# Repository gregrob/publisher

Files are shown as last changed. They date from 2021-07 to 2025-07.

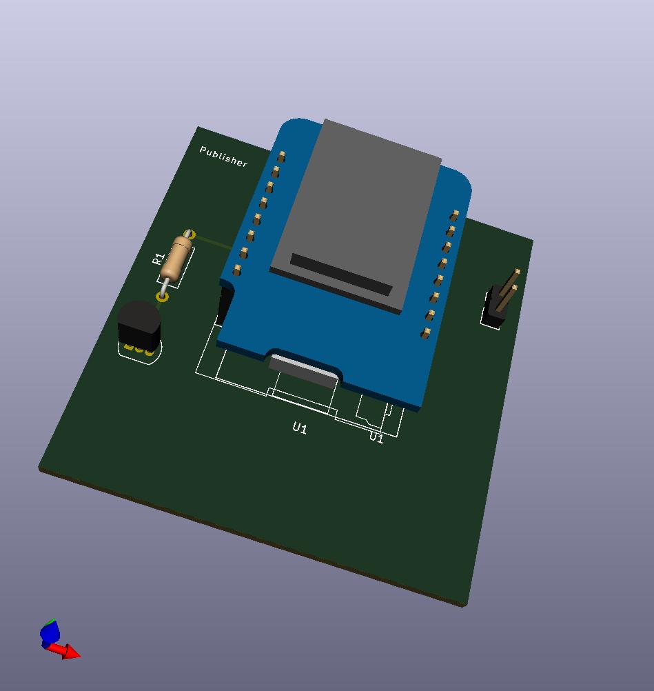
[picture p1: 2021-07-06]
hardware/publisher/publisher.jpg

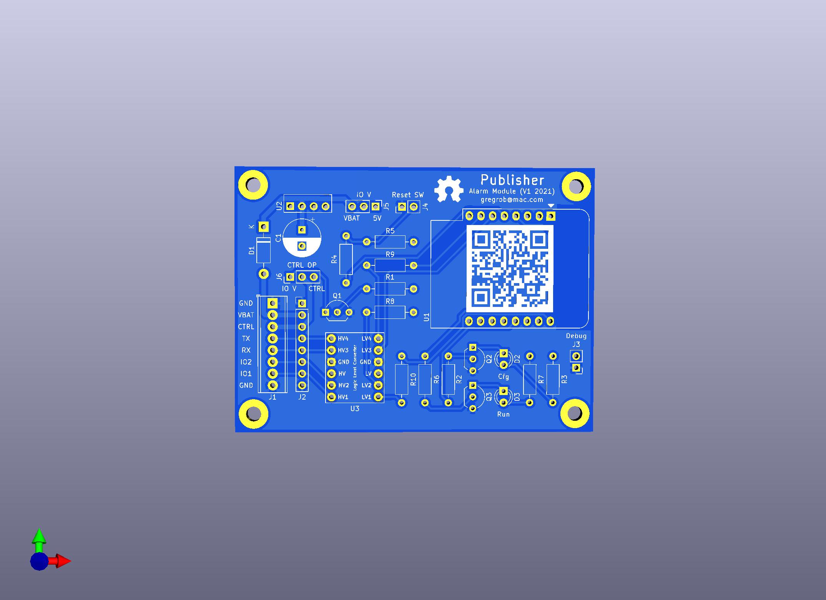
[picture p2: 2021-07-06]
hardware/publisher/publisher-2jpg.jpg

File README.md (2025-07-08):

# Publisher

IoT gadget that sends / receives / acts on MQTT messages.

Using arduino library and PlatformIO to allow easy porting between ESP8266 / ESP32 / Raspberry Pi Pico.

Applications:

1. Alarm interface
* PIR states.
* Remote arm / disarm.

2. Garage door
* Door state.
* Open / Close.

3. Tank Water Level
* Water level.

## Documentation

Detailed technical documentation for various system components and features:

### Device Control & Management
- **[Reset Control via MQTT](docs/reset_control/reset_control_mqtt.md)** - Remote device reset functionality including WiFi and NVM clearing

### Hawkbit
- **[Hawkbit Client Flow](docs/hawkbit/hawkbit_client_flow.svg)** - Over-the-air (OTA) update client flow diagram showing device update process with hawkbit

### Communication Protocols
- *(coming soon)*

### Hardware Interfaces  
- *(coming soon)*

### System Features
- *(coming soon)*

### Development & Debugging
- *(coming soon)*

### Integration Examples
- *(coming soon)*

## Software Architecture
Software Architecture

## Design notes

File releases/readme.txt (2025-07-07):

--------------------------------------------------
000.006.005
2021-06-06

- First release for the alarm module.
- Currently running on the alarm module.

--------------------------------------------------
000.007.005
2022-08-20

- First release to include the garage door.
- Includes test code for the ultrasonics.

--------------------------------------------------

000.007.006
2022-09-08

- The input debounce configuration was incorrectly
  set to 0.  This releases fixes this and 
  configures the reset pin to 40ms and alarm 
  sounder pin to 500ms.

--------------------------------------------------

000.007.007
2024-07-07

- Release to include pub-garage-door-active-v2
- Pin platform to espressif8266@2.6.3

- BUG: Runtime is in ms not us as variable would
       suggest

--------------------------------------------------

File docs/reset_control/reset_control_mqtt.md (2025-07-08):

# Reset Control via MQTT

This document describes how to control device resets remotely using MQTT commands in the Publisher project.

## Overview

The Publisher device supports remote reset functionality through MQTT messages. This allows for different types of resets to be triggered remotely, from a simple restart to clearing WiFi credentials and NVM settings.

## MQTT Topic Structure

The device subscribes to the following MQTT topic for reset commands:

```
[mqtt_prefix]/[hostname]/module command
```

Where:
- `mqtt_prefix`: Configured MQTT topic root (from NVM settings)
- `hostname`: Device hostname (derived from WiFi module details)

## Reset Command Format

Reset commands are sent as JSON messages with the following structure:

```json
{
  "reset": <reset_type>
}
```

Where `<reset_type>` is an integer representing the type of reset to perform.

## Reset Types

The following reset types are supported:

| Reset Type | Value | Description |
|---|---|---|
| `rstTypeNone` | 0 | No reset (cancels pending reset) |
| `rstTypeReset` | 1 | Simple device restart |
| `rstTypeResetWiFi` | 2 | Restart + clear WiFi settings |
| `rstTypeResetWiFiNvm` | 3 | Restart + clear WiFi + NVM settings |

## Reset Behavior

### Simple Reset (`rstTypeReset` = 1)
- Performs immediate device restart
- Preserves all configuration settings
- Device will reconnect with existing settings

### WiFi Reset (`rstTypeResetWiFi` = 2)
- Clears WiFi configuration settings
- Performs device restart
- Device will enter WiFi configuration mode on next boot
- NVM settings are preserved

### WiFi + NVM Reset (`rstTypeResetWiFiNvm` = 3)
- Clears all WiFi configuration settings
- Clears all NVM (Non-Volatile Memory) settings
- Performs device restart
- Device will enter initial setup mode

## Example Commands

### Simple Restart
```bash
# Using mosquitto_pub
mosquitto_pub -h <mqtt_broker> -t "devices/publisher001/module command" -m '{"reset": 1}'
```

### Clear WiFi and Restart
```bash
mosquitto_pub -h <mqtt_broker> -t "devices/publisher001/module command" -m '{"reset": 2}'
```

### Factory Reset (Clear WiFi + NVM)
```bash
mosquitto_pub -h <mqtt_broker> -t "devices/publisher001/module command" -m '{"reset": 3}'
```

### Cancel Pending Reset
```bash
mosquitto_pub -h <mqtt_broker> -t "devices/publisher001/module command" -m '{"reset": 0}'
```

## Reset State Machine

The reset controller implements a state machine with the following states:

- **stmResetIdle**: Normal operation, waiting for reset requests
- **stmReset**: Reset type 1 requested
- **stmResetWiFi**: Reset type 2 requested  
- **stmResetWiFiNvm**: Reset type 3 requested
- **stmResetAllowCancel**: Cancellation period before executing reset
- **stmResetAction**: Performing the actual reset

## Physical Reset Switch Integration

The system also supports physical reset switch functionality:

- **2 seconds**: Triggers WiFi reset (`rstTypeResetWiFi`)
- **8 seconds**: Triggers WiFi + NVM reset (`rstTypeResetWiFiNvm`)
- Physical switch can be enabled/disabled via configuration

## Cancellation Window

When a reset is requested via MQTT, there is a cancellation period before the reset is executed:

- **Fast cancel**: 2 seconds for switch-triggered resets
- **Slow cancel**: 5 seconds for MQTT-triggered resets

During this window, sending `{"reset": 0}` will cancel the pending reset.

## Debug Information

Reset operations generate debug messages that can be monitored:

```
resetCtrl: State change to <state> (request type <type>)
resetCtrl: Rebooting unit + clearing WiFi settings...
resetCtrl: Reset will occur in Xs
```

## Priority Handling

The reset controller processes requests in the following priority order:

1. **OTA Reboot**: Highest priority when OTA update requires restart
2. **MQTT Reset Request**: Medium priority for remote reset commands
3. **Physical Switch**: Lowest priority for manual reset operations

## Error Handling

- Invalid reset type values are ignored
- Reset requests are only accepted when the state machine is in idle state
- Message buffer overflow protection prevents malformed commands
- JSON parsing errors are logged and rejected

## Security Considerations

- MQTT authentication should be enabled on the broker
- Consider using TLS/SSL for MQTT connections
- Physical access to the reset switch provides full device control
- WiFi + NVM reset will require device reconfiguration

## Integration Example

Here's a Python example for sending reset commands:

```python
import paho.mqtt.client as mqtt
import json

def send_reset_command(mqtt_client, device_hostname, reset_type):
    """
    Send a reset command to a device
    
    Args:
        mqtt_client: Connected MQTT client
        device_hostname: Target device hostname
        reset_type: Reset type (0-3)
    """
    topic = f"devices/{device_hostname}/module command"
    payload = json.dumps({"reset": reset_type})
    
    mqtt_client.publish(topic, payload)
    print(f"Sent reset command {reset_type} to {device_hostname}")

# Usage
client = mqtt.Client()
client.connect("mqtt_broker_address", 1883, 60)

# Simple restart
send_reset_command(client, "publisher001", 1)

# Factory reset
send_reset_command(client, "publisher001", 3)
```

## Related Modules

- **MQTT Module**: Handles message reception and topic subscription
- **WiFi Module**: Manages WiFi configuration and connection
- **NVM Module**: Handles non-volatile memory operations
- **Debug Module**: Provides logging and status reporting
- **Status Controller**: Manages LED status indicators during reset operations

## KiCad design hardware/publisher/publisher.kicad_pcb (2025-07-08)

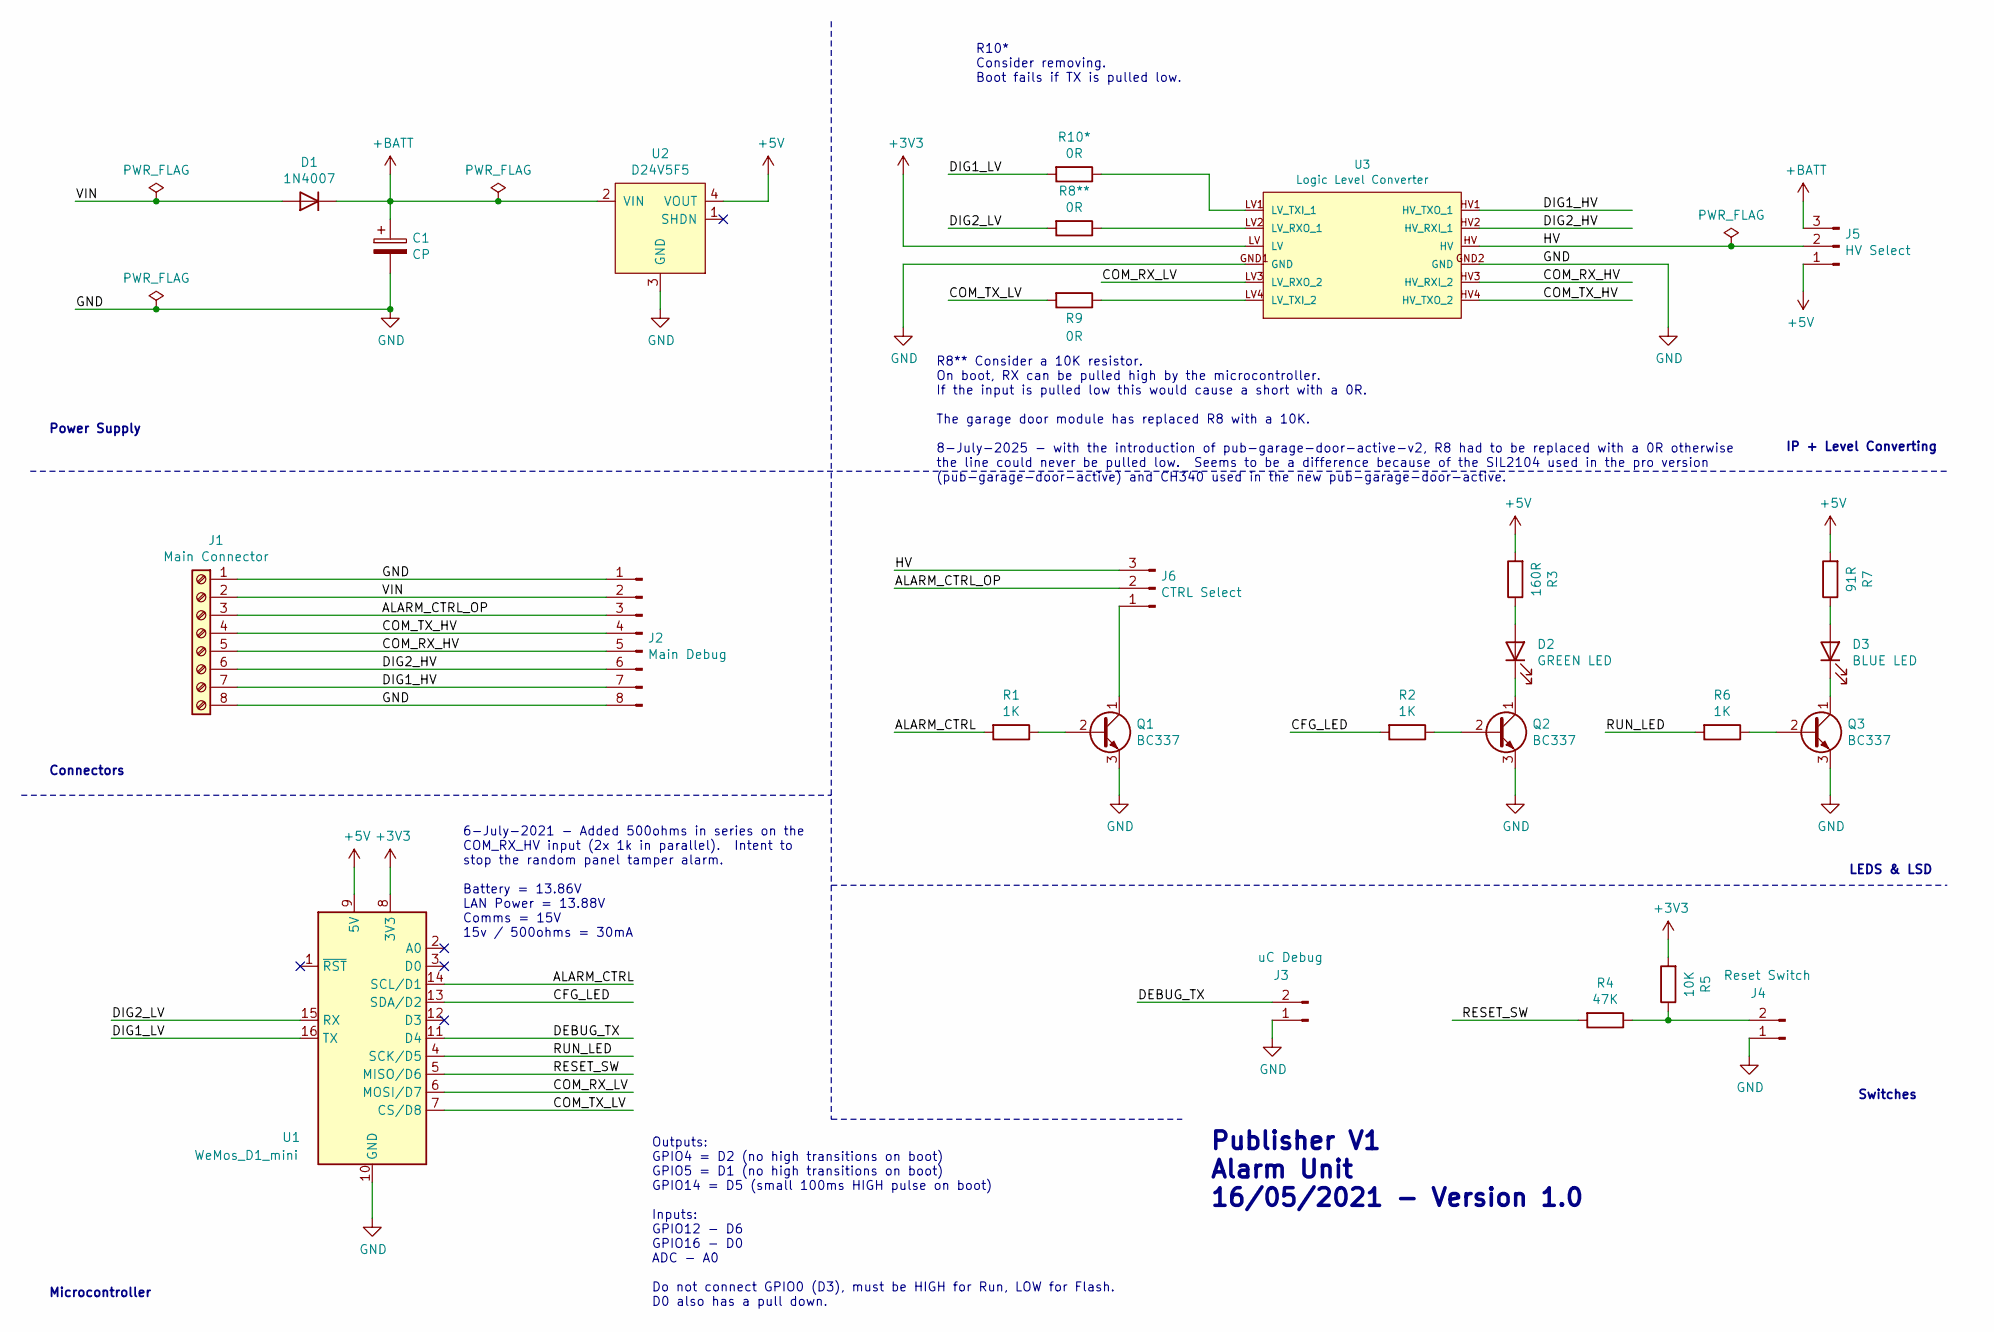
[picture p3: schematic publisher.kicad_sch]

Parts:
C1: CP; CP_Radial_D8.0mm_P3.50mm
D1: 1N4007; D_DO-41_SOD81_P10.16mm_Horizontal
D2: GREEN LED; LED_D3.0mm_Clear
D3: BLUE LED; LED_D3.0mm_Clear
J1: Main Connector; TerminalBlock_Phoenix_MPT-0,5-8-2.54_1x08_P2.54mm_Horizontal
J2: Main Debug; PinHeader_1x08_P2.54mm_Vertical
J3: uC Debug; PinHeader_1x02_P2.54mm_Vertical
J4: Reset Switch; PinHeader_1x02_P2.54mm_Vertical
J5: HV Select; PinHeader_1x03_P2.54mm_Vertical
J6: CTRL Select; PinHeader_1x03_P2.54mm_Vertical
Q1, Q2, Q3: BC337; TO-92_Inline_Wide
R1, R2, R6: 1K; R_Axial_DIN0207_L6.3mm_D2.5mm_P10.16mm_Horizontal
R3: 160R; R_Axial_DIN0207_L6.3mm_D2.5mm_P10.16mm_Horizontal
R4: 47K; R_Axial_DIN0207_L6.3mm_D2.5mm_P10.16mm_Horizontal
R5: 10K; R_Axial_DIN0207_L6.3mm_D2.5mm_P10.16mm_Horizontal
R7: 91R; R_Axial_DIN0207_L6.3mm_D2.5mm_P10.16mm_Horizontal
R8**, R9, R10*: 0R; R_Axial_DIN0207_L6.3mm_D2.5mm_P10.16mm_Horizontal
U1: WeMos_D1_mini; WEMOS_D1_mini_light
U2: D24V5F5
U3: Logic Level Converter; SPARKFUN_LOGIC_LEVEL_CONVERTER

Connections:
+3V3: R5.2, U1.8 (3V3), U3.LV
+5V: J5.1, R3.2, R7.2, U1.9 (5V), U2.4 (VOUT)
+BATT: C1.1, D1.1 (K), J5.3, U2.2 (VIN)
/ALARM_CTRL: R1.2, U1.14 (SCL/D1)
/ALARM_CTRL_OP: J1.3, J2.3, J6.2
/CFG_LED: R2.2, U1.13 (SDA/D2)
/COM_RX_HV: J1.5, J2.5, U3.HV3 (HV_RXI_2)
/COM_RX_LV: U1.6 (MOSI/D7), U3.LV3 (LV_RXO_2)
/COM_TX_HV: J1.4, J2.4, U3.HV4 (HV_TXO_2)
/COM_TX_LV: R9.2, U1.7 (CS/D8)
/DEBUG_TX: J3.2, U1.11 (D4)
/DIG1_HV: J1.7, J2.7, U3.HV1 (HV_TXO_1)
/DIG1_LV: R10*.2, U1.16 (TX); also elsewhere on the board
/DIG2_HV: J1.6, J2.6, U3.HV2 (HV_RXI_1)
/DIG2_LV: R8**.2, U1.15 (RX); also elsewhere on the board
/HV: J5.2, J6.3, U3.HV
/RESET_SW: R4.2, U1.5 (MISO/D6)
/RUN_LED: R6.2, U1.4 (SCK/D5)
/VIN: D1.2 (A), J1.2, J2.2
GND: C1.2, J1.1, J1.8, J2.1, J2.8, J3.1, J4.1, Q1.3 (E), Q2.3 (E), Q3.3 (E), U1.10 (GND), U2.3 (GND), U3.GND1 (GND), U3.GND2 (GND)
unnamed: D2.1 (K), Q2.1 (C)
unnamed: D2.2 (A), R3.1
unnamed: D3.1 (K), Q3.1 (C)
unnamed: D3.2 (A), R7.1
unnamed: J4.2, R4.1, R5.1
unnamed: J6.1, Q1.1 (C)
unnamed: Q1.2 (B), R1.1
unnamed: Q2.2 (B), R2.1
unnamed: Q3.2 (B), R6.1
unnamed 29: R8**.1, U3.LV2 (LV_RXO_1); also elsewhere on the board
unnamed: R9.1, U3.LV4 (LV_TXI_2)
unnamed 31: R10*.1, U3.LV1 (LV_TXI_1); also elsewhere on the board

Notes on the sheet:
Power Supply
IP + Level Converting
R8** Consider a 10K resistor. On boot, RX can be pulled high by the microcontroller. If the input is pulled low this would cause a short with a 0R. The garage door module has replaced R8 with a 10K. 8-July-2025 - with the introduction of pub-garage-door-active-v2, R8 had to be replaced with a 0R ot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
Outputs: GPIO4 = D2 (no high transitions on boot) GPIO5 = D1 (no high transitions on boot) GPIO14 = D5 (small 100ms HIGH pulse on boot) Inputs: GPIO12 - D6 GPIO16 - D0 ADC - A0 Do not connect GPIO0 (D3), must be HIGH for Run, LOW for Flash. D0 also has a pull down.
6-July-2021 - Added 500ohms in series on the COM_RX_HV input (2x 1k in parallel). Intent to stop the random panel tamper alarm. Battery = 13.86V LAN Power = 13.88V Comms = 15V 15v / 500ohms = 30mA
Connectors
Switches
LEDS & LSD
Publisher V1 Alarm Unit 16/05/2021 - Version 1.0
R10* Consider removing. Boot fails if TX is pulled low.
Microcontroller

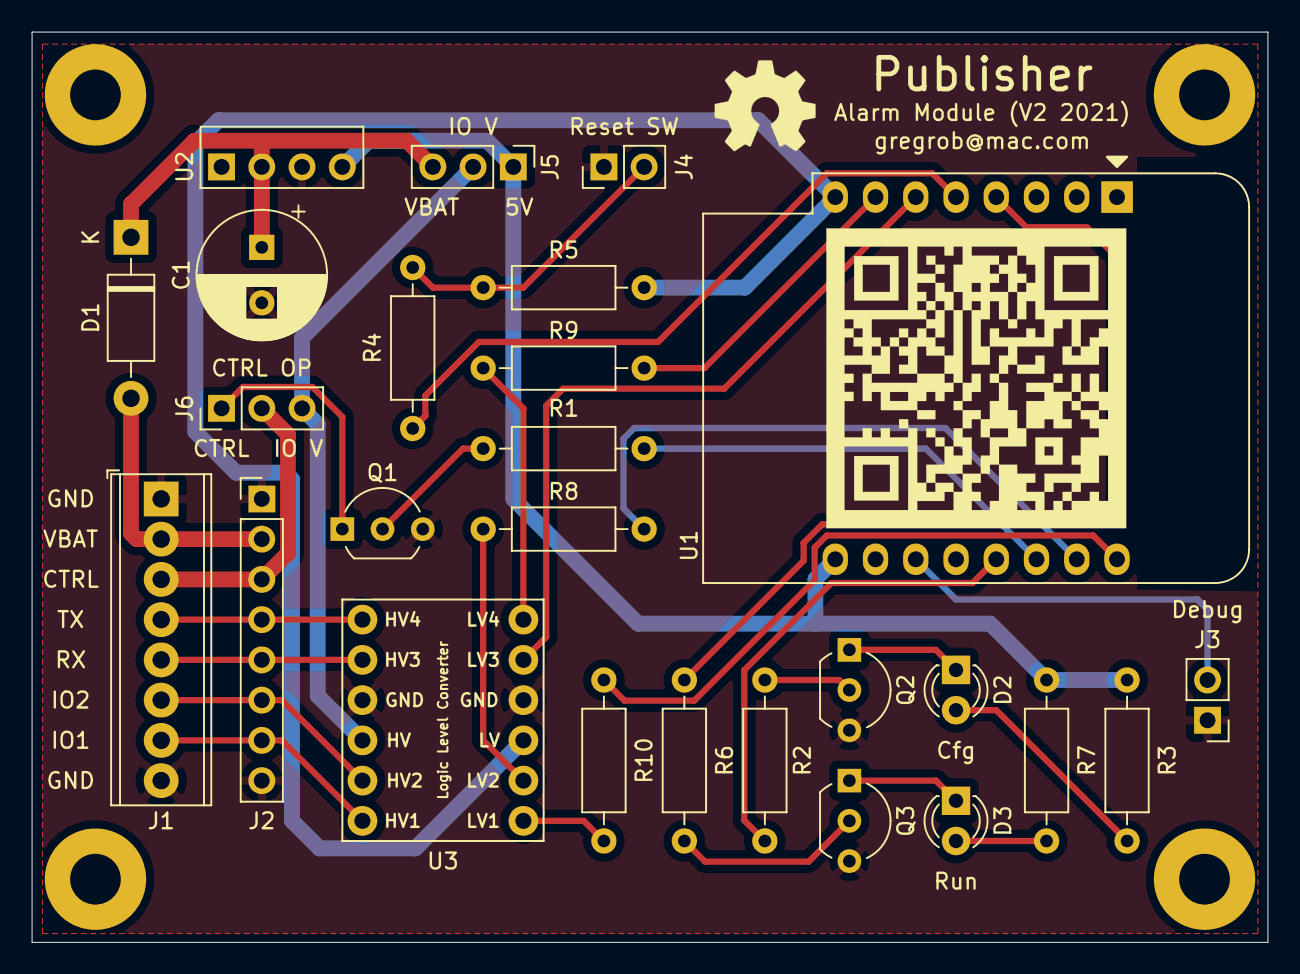
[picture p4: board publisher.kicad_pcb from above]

Board: 2 copper layers, 78.0 x 57.5 mm, 30 parts (0 on the bottom side), 32 nets.

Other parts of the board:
H1, H2, H3, H4: MountingHole_3.2mm_M3_Pad
R8, R10: 0R; R_Axial_DIN0207_L6.3mm_D2.5mm_P10.16mm_Horizontal

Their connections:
/DIG1_LV: R10.2; also elsewhere on the board
/DIG2_LV: R8.2; also elsewhere on the board
unnamed 29: R8.1; also elsewhere on the board
unnamed 31: R10.1; also elsewhere on the board

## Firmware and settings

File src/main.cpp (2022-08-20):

#include <Arduino.h>
#include <TaskScheduler.h>

#include "debug.h"
#include "version.h"
#include "wifi.h"
#include "ota.h"
#include "mqtt.h"
#include "alarm.h"
#include "runtime.h"

#include "nvm_cfg.h"
#include "inputs.h"
#include "outputs.h"

#include "reset_ctrl.h"
#include "status_ctrl.h"
#include "hawkbit_client.h"
#include "ultrasonics_ctrl.h"
#include "garage_door.h"

// Local function definitions
void periodicMessageTx(void);


// Create the Scheduler that will be in charge of managing the tasks
static Scheduler scheduler;

// Debug serial port
static HardwareSerial *debugSerialPort;

// Alarm serial port
static HardwareSerial *alarmSerialPort;

// Create tasks
Task wifiStatus(30000, TASK_FOREVER, &checkWifi);
Task mqttClientTask(100, TASK_FOREVER, &mqttClientLoop);
Task mqttMessageTask(10000, TASK_FOREVER, &mqttMessageLoop);

Task taskInputsCyclic(INPUTS_CYCLIC_RATE, TASK_FOREVER, &inputsCyclicTask);
Task taskOutputsCyclic(OUTPUTS_CYCLIC_RATE, TASK_FOREVER, &outputsCyclicTask);
Task taskResetCtrl(RESET_CTRL_CYCLIC_RATE, TASK_FOREVER, &restCtrlStateMachine);
Task taskStatusCtrl(STATUS_CTRL_CYCLIC_RATE, TASK_FOREVER, &statusCtrlStateMachine);
Task taskHawkbitCtrl(HAWKBIT_CLIENT_CYCLIC_RATE, TASK_FOREVER, &hawkbitClientStateMachine);
Task taskAlarmCyclic(ALARM_CYCLIC_RATE, TASK_FOREVER, &alarmCyclicTask);
Task taskUltrasonicsCtrl(ULTRASONICS_CTRL_CYCLIC_RATE, TASK_FOREVER, &ultrasonicCtrlStateMachine);
Task taskGarageDoorCyclic(GARAGE_DOOR_CYCLIC_RATE, TASK_FOREVER, &garageDoorCyclicTask);
Task taskPeriodicMessageTx(30000, TASK_FOREVER, &periodicMessageTx);

void testo() {
    //static bool pino = true;
    //Serial1.println(inputsReadInputByName(resetSw));
    //if(inputsReadInput(resetSw)) {ESP.restart();}
    //hawkbitClientCyclicTask();
    //analogWrite(RX, 1024);
    //digitalWrite(RX, pino);
    //if(pino) pino = false;
    //else pino = true;
}

Task switcher(1000, TASK_FOREVER, &testo);

void setup(void) {
    
    // STEP 0 - Identify variant
    wifiIdentifyModule();

    // STEP 1 - Setup debug serial
    debugSerialPort = debugSetSerial(&Serial1);
    debugSerialPort->begin(115200);
    debugSerialPort->println();    
    
    // STEP 2 - Set up basic software
    nvmInit();
    inputsInit();
    outputsInit();
    versionInit();

    // STEP 3 - Set up the applications
    hawkbitClientInit();
    restCtrlInit();
    statusCtrlInit();

    if (getWiFiModuleDetails()->moduleHostType == alarmModule) {
        // Set up the alarm interface
        alarmSerialPort = alarmInit(&Serial);
        // Put the serial pins on D7 = Rx and D8 = Tx.
        alarmSerialPort->swap();
    }
    else if (getWiFiModuleDetails()->moduleHostType == ultrasonicsModule) {
        ultrasonicsCtrlInit();
    }
    else if (getWiFiModuleDetails()->moduleHostType == garageDoorModule) {
        garageDoorInit();
    }

    // Set-up wifi
    setupWifi();

    // Set-up ota
    otaSetup();

    // Set-up mqtt
    mqttSetup();

        
    // Add scheduler tasks and enable
    scheduler.addTask(wifiStatus);        
    scheduler.addTask(mqttClientTask);
    scheduler.addTask(mqttMessageTask);
   
    scheduler.addTask(taskInputsCyclic);
    scheduler.addTask(taskOutputsCyclic);
    scheduler.addTask(taskResetCtrl);
    scheduler.addTask(taskStatusCtrl);
    scheduler.addTask(taskHawkbitCtrl);
    scheduler.addTask(taskPeriodicMessageTx);
    scheduler.addTask(taskAlarmCyclic);
    scheduler.addTask(taskUltrasonicsCtrl);
    scheduler.addTask(taskGarageDoorCyclic);

    wifiStatus.enable();
    mqttClientTask.enable();
    mqttMessageTask.enable();

    taskInputsCyclic.enable();
    taskOutputsCyclic.enable();
    taskResetCtrl.enable();
    taskStatusCtrl.enable();
    taskHawkbitCtrl.enable();
    taskPeriodicMessageTx.enable();
    
    if (getWiFiModuleDetails()->moduleHostType == alarmModule) {
        taskAlarmCyclic.enable();
    }
    else if (getWiFiModuleDetails()->moduleHostType == ultrasonicsModule) {
        taskUltrasonicsCtrl.enable();
    }
    else if (getWiFiModuleDetails()->moduleHostType == garageDoorModule) {
         taskGarageDoorCyclic.enable();           
    }

    scheduler.addTask(switcher);
    switcher.enable();



    randomSeed(micros());
}


void loop(void) { 
    // Handle runtime measurements
    runtimeMeasureAverageuS();
    runtimeMeasurePeakuS();

    // Handle tasks
    otaLoop();
    
    if (getWiFiModuleDetails()->moduleHostType == alarmModule) {
        alarmBackgroundLoop();
    }

    scheduler.execute();
}


/**
    Transmit periodic messages.
*/
void periodicMessageTx(void) {

    // System messages
    versionTransmitVersionMessage();
    runtimeTransmitRuntimeMessage();
    wifiTransmitWifiMessage();
    nvmTransmitStatusMessage();
    
    // Only handle alarm messages if this is an alarm unit
    if (getWiFiModuleDetails()->moduleHostType == alarmModule) {
        alarmTransmitAlarmAllMessage();
    }
    else if (getWiFiModuleDetails()->moduleHostType == ultrasonicsModule) {
        
    }
    else if (getWiFiModuleDetails()->moduleHostType == garageDoorModule) {
         garageDoorTransmitAlarmAllMessage();           
    }
}

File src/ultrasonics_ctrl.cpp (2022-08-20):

// THIS IS TEST CODE, NOT VALIDATED


#include <Arduino.h>

#include "ultrasonics_ctrl.h"

#include "utils.h"
#include "debug.h"
#include "nvm_cfg.h"


// Set the module call interval
#define MODULE_CALL_INTERVAL                    ULTRASONICS_CTRL_CYCLIC_RATE

// Enable extra debug information
#define ULTRASONICS_CTRL_DETAILED_DEBUG

// Time to stay in idle state in S
#define ULTRASONICS_CTRL_IDLE_TIME_RST_S        (1)

// Time to wait between sucessive measurements in S
#define ULTRASONICS_CTRL_INTERMEASURE_DELAY_S   (0.05)

// Min reading possible
#define ULTRASONIC_CTRL_MIN_READING_POSSIBLE    (25)

// Max reading possible
#define ULTRASONIC_CTRL_MAX_READING_POSSIBLE    (450)

// Measurement re-tries (always +1 so 5 will be 6 total)
#define ULTRASONIC_CTRL_MEASUREMENT_RETRY_RST   (5)

// Size of the filter for the measurements
#define ULTRASONIC_CTRL_FILTER_SIZE             (6)

// How many extreme values in the filter to ignore
#define ULTRASONIC_CTRL_EXTREME_IGNORE          (2)

// Make sure that the number of extreme values to ignore leaves at least 1 measurement to average
static_assert((ULTRASONIC_CTRL_FILTER_SIZE - (ULTRASONIC_CTRL_EXTREME_IGNORE * 2)) >= 1, "ULTRASONIC_CTRL_EXTREME_IGNORE is too big in comparison to ULTRASONIC_CTRL_FILTER_SIZE");


// Module name for debug messages
static const char* ultrasonicsCtrlModuleName = "ultrasonicsCtrl";

// Output pin for ultrasonic trigger
static const uint8_t outputMapTrigger = RX;

// Input pin for ultrasonic echo
static const uint8_t inputMapEcho = D7;

// Ultrasonics controller state machine state names
static const char * ultrasonicsCtrlStateNames[] {
    "stmUltrasonicsRestart",
    "stmUltrasonicsIdle",
    "stmUltrasonicsMeasure"
};

// Current state
static ultrasonicsCtrlStm ultrasonicsCtrlCurrentState;

// Total number of measurements
static unsigned long ultrasonicsCtrlMeasurements = 0;

// Total number of errors in measurement - low side
static unsigned long ultrasonicsCtrlErrorsLow = 0;

// Total number of errors in measurement - high side
static unsigned long ultrasonicsCtrlErrorsHigh = 0;


/**
    Ultrasonics controller init.
*/
void ultrasonicsCtrlInit(void) {

    // Set-up direct access to the pins, not filtered
    pinMode(outputMapTrigger, OUTPUT);        
    pinMode(inputMapEcho, INPUT);
    
    // TODO: Check if this is really necessary, seems suss on an input
    digitalWrite(inputMapEcho, HIGH);
}


/**
    Take a ultrasonic measurement.
    Blocking call.
    
    @return        ranging data in CM.
*/
static uint32_t ultrasonicsCtrlMeasureDistance(void) {
    
    // Pulse return time
    uint32_t pulseReturnTimeUS;

    // Distance in cm
    uint32_t distanceCM;

    // Set the trigger pin to low for 2uS
    digitalWrite(outputMapTrigger, LOW);
    delayMicroseconds(2);
    
    // Send a 15uS high to trigger ranging (example was 10uS)
    digitalWrite(outputMapTrigger, HIGH); 
    delayMicroseconds(15);
    
    // Send pin low again
    digitalWrite(outputMapTrigger, LOW);
  
    // Read in times pulse
    pulseReturnTimeUS = pulseIn(inputMapEcho, HIGH, 26000);
    
    // Calculate the distance
    distanceCM = pulseReturnTimeUS / 58;

    // Increment measurement counter
    ultrasonicsCtrlMeasurements++;

    return(distanceCM);
}


/**
    Filter outside of range ultrasonic measurement.

    @param[in]     rawDistance raw distance measured.
    @param[in]     rangeFilteredDistance pointer to where range filtered distance is to be stored.
    @return        true when rawDistance is within range.
*/
static bool ultrasonicsCtrlRangeFilter(const uint32_t rawDistance, uint32_t * const rangeFilteredDistance) {

    // Was the rawDistance within range and rangeFilteredDistance updated?
    bool distanceWithinRange = false;

    // Reading outside range - low
    if (rawDistance <= ULTRASONIC_CTRL_MIN_READING_POSSIBLE) {
        ultrasonicsCtrlErrorsLow++;
    }

    // Reading outside range - high
    else if(rawDistance >= ULTRASONIC_CTRL_MAX_READING_POSSIBLE) {
        ultrasonicsCtrlErrorsHigh++;
    }

    // Distance within range
    else {
        *rangeFilteredDistance = rawDistance;
        distanceWithinRange = true;
    }

    return(distanceWithinRange);
}


/**
    Swap elements in an array of uint32_t's.

    @param[in]     xp pointer to first array element to be swapped.
    @param[in]     yp pointer to second array element to be swapped.
*/
static void ultrasonicsCtrlArrayElementSwap(uint32_t * const xp, uint32_t * const yp)
{
    uint32_t temp = *xp;
    *xp = *yp;
    *yp = temp;
}
 

/**
    Sort the items in an array from smallest to biggest.

    @param[in]     array pointer to the array to sort.
    @param[in]     arraySize size of the array.
*/
static void ultrasonicsCtrlSelectionSort(uint32_t * const array, const uint32_t arraySize)
{
    uint32_t minimumItemIndex;
 
    // One by one move boundary of unsorted subarray
    for (unsigned int i = 0; i < arraySize - 1; i++) {
 
        // Find the minimum element in unsorted array
        minimumItemIndex = i;
        for (unsigned int j = i + 1; j < arraySize; j++) {
            if (array[j] < array[minimumItemIndex]) {
                minimumItemIndex = j;
            }
        }
 
        // Swap the found minimum element with the first element
        ultrasonicsCtrlArrayElementSwap(&array[minimumItemIndex], &array[i]);
    }
}
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

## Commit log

2021-03-18 First cut of OTA software, still WIP.
2021-03-26 Improvements to the alarm including arm/disarm.
2021-03-27 One shot alarm arm / disarm.
2021-04-13 Initial NVM driver.
2021-04-16 NVM handler tracking errors.
    [nvm_cfg.h]
2021-04-17 Output driver improvements.
2021-04-17 Configs for LED brightness and control.
2021-04-19 Integration of reset handler.
    [main.cpp, wifi.cpp]
2021-04-19 Removed blinking run LED.
2021-04-24 Initial cut of hawkbit.
2021-06-05 Bug fix for module identified too late in init.
    [main.cpp, wifi.cpp]
2021-07-06 Hardware (in kicad) added.
    [publisher-B_Cu.gbl, publisher-B_Mask.gbs, publisher-B_Paste.gbp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]
2022-08-20 added garage door module and ultrasonics test code
2022-08-23 schematic notes for 10k on R8 and removing R10
    [publisher.sch]
2025-07-07 pin the framework version to espressif8266@2.6.3 as new versions need a bit rework of include files
2025-07-07 kicad updated project files
2025-07-08 upgraded sch and pcb to kicad 8
    [publisher.kicad_pcb, publisher.kicad_sch]
